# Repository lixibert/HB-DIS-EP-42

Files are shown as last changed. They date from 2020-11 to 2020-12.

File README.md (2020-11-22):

# HB-DIS-EP-42 

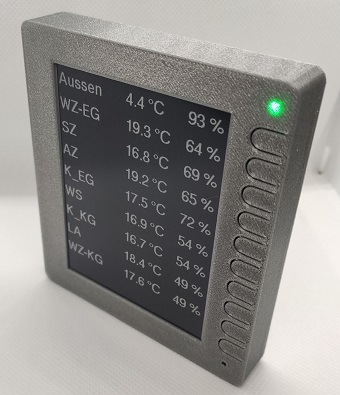
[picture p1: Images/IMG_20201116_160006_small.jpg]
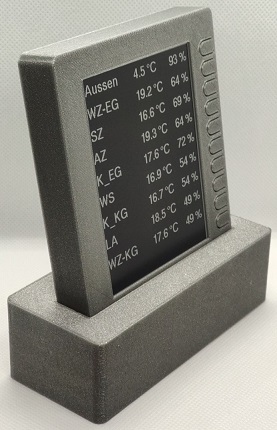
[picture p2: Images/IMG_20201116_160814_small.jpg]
 

Die Infos hier beziehen sich auf Jérômes Projekt ePaper Display HB-Dis-EP-42BW  
[Original HB-Dis-EP-42BW](https://github.com/jp112sdl/HB-Dis-EP-42BW)

Support thread: https://homematic-forum.de/forum/viewtopic.php?f=76&t=61624

## Danke an  

Marco (stan23) für das ursprüngliche Leiterplattendesign welches Ausgangspunkt für diese Variante war  
papa für die Bereitstellung der AskSinPP Library  
TomMajor für die guten Tipps und den genialen Script-Helper  
Jérôme für Alles ;-)  

# Warum noch eine Variante?
Einerseits hat sich das e-Paper-Display von Waveshare geändert (Rev.2.1) und ich  wollte eine Gehäusevariante für die Wandmontage haben.
Hier hätten normale AA Batterien zu viel Platz beansprucht und das Gehäuse wäre entweder zu dick
oder zu lang geworden. Also musste eine Lösung mit Li-Po Akku her.

Außerdem hat man mehrere Möglichkeiten zur Stromversorgung  

- AA/AAA Batterien oder Akkus mit/ohne Stepup Regler  
- Li-Po Akku  
- Netzbetrieb mit 5V Netzteil  über Micro-USB Buchse  

Während des Ladevorgangs leuchten beide Leds (Duoled) solange bis der Akku vollgeladen ist. 

# Sketch  
Die Firmware stammt von Jérôme und wurde nur durch den Teil für den Li-Po Akku erweitert.  
Dazu einfach im Code  
`#define LIPO`  
auskommentieren. (Standard ist bereits auskommentiert)  
Für die Varianten ohne Li-Po kann man wahlweise auch die originale Version von Jérôme laden.    
https://github.com/jp112sdl/HB-Dis-EP-42BW/blob/master/HB-Dis-EP-42BW.ino

# Schaltung
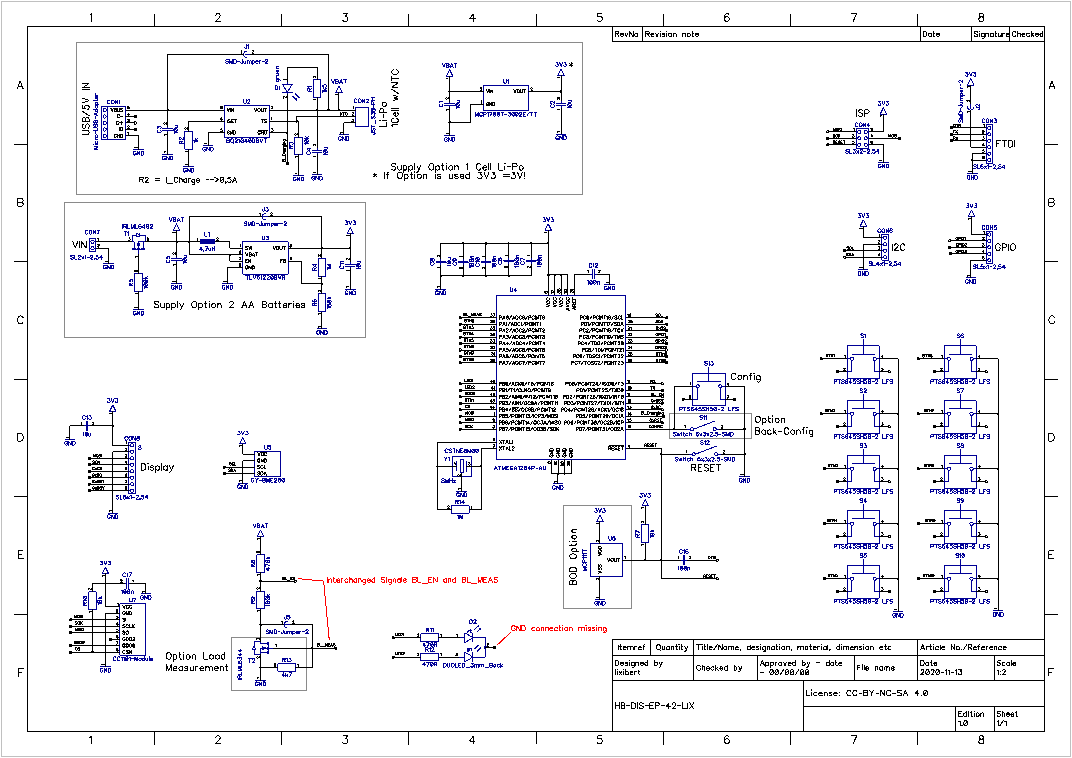
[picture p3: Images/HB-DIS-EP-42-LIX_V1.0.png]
  
In der ersten Version gibt es leider noch 2 Fehler im Schaltplan (rot markiert) ,  
die sich jedoch auf der Platine sehr leicht beheben lasssen.  
Die beiden Signale um die Batteriespannung zu messen (BL_EN und BL_MEAS) sind vertauscht.  
Auf der Platine muß daher R8 (470k) und R9 (100k) etwas anders bestückt werden.  
Lötjumper J5 muß geschlossen werden.  

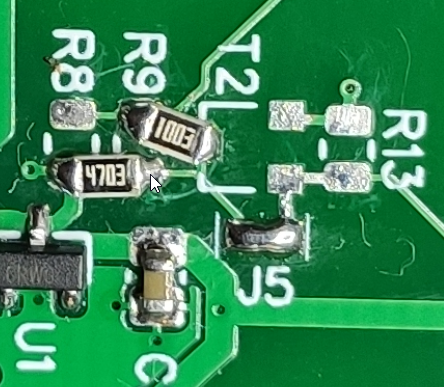
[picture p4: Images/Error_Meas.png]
  
Bei der Duoled fehlt die Masseanbindung. Dazu muß nur etwas Lötstopplack weggekratzt werden  
und mit Lötzinn verbunden werden.  
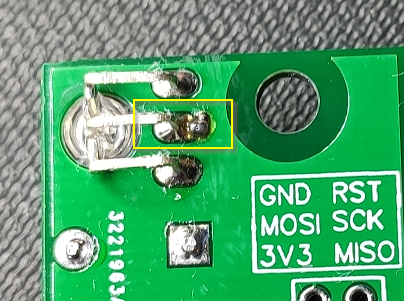
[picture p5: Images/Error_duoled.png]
  
Bei Bedarf werde ich die Daten noch bereinigen und eine neue Version erstellen.  
Zur Zeit habe ich jedoch noch einige Leiterplatten vorrätig, so dass da für mich keine Notwendigkeit  besteht.  

# Platine  
[**Gerberdaten**](PCB/HB-DIS-EP-42-LIX_gerberx2.zip)  
[**Stückliste**](PCB/Stückliste_HB-DIS-EP-42_V1.0.pdf)  

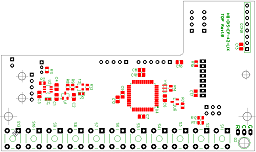
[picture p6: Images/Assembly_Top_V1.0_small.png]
  

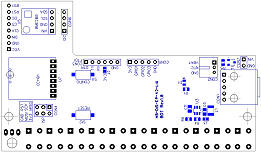
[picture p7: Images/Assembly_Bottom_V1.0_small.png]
  

# Mechanik
Das Gehäuse besteht  aus einem [Frontrahmen](Mechanik/Frontrahmen.stl) in welchem die Leiterplatte mit dem  Display eingeklebt wird  
und aus einer [Rückwand](Mechanik/Rückwand.stl) die einfach auf den Frontrahmen geclipst wird.  
Auf die Innenseite der Rückwand können z. B. auch Magnete geklebt werden.  
In meinem Fall befindet sich eine Holzkonsole an der Wand, in die ebenfalls Magnete eingklebt wurden.  
Somit kann man das Display sowohl als Tischmodel, als auch an der Wand benutzen.   

Zusätzlich gibt es noch einen [Sockel](Mechanik/Sockel.stl) mit [Batteriefach](Sockelverschluss.stl) an der Unterseite.  
Es gibt die Möglichkeit im Frontrahmen und am Sockel Magnete (10x5x2mm) einzukleben.  
Damit sitzt das Display dann fest im Sockel.  
Der Sockel wird für die Variante mit AA/AAA Batterien zwingend benötigt, da nur hier genug Platz für die Batteriebox ist.  
Die max. Abmessungen für eine Batteriebox sind l/b/h = 114 x 44 x 20mm.  
Somit ist eine Montage an der Wand nur mit Li-Po Akku möglich.  

# Aufbau  
**Wichtig! Display und Platine erst nach der Verschraubung verlöten**  
Das Display wird mit der Platine mit 2 Senkkopfschrauben M3x10 verschraubt.  
Wichtig ist, das der Abstand zwischen Display und Platine 2mm beträgt, damit die Taster bündig mit dem Frontrahmen sind!  
Die Schrauben sollten noch nicht ganz fest angezogen werden.  

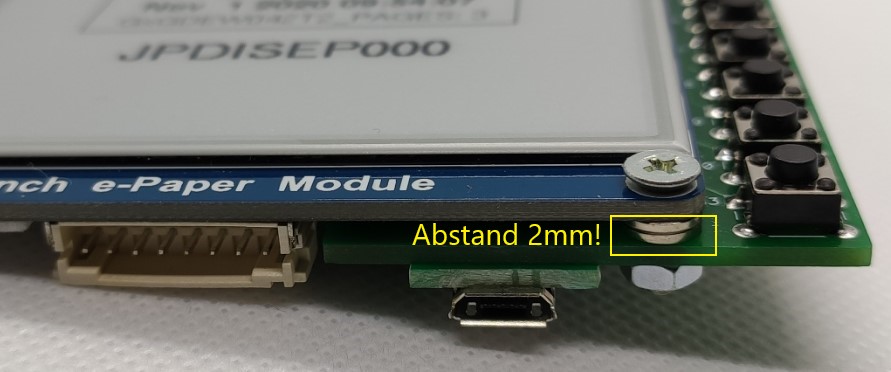
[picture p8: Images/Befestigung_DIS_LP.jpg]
  

Nun werden die 2 Magnete in den Frontrahmen an die Unterseite geklebt.  

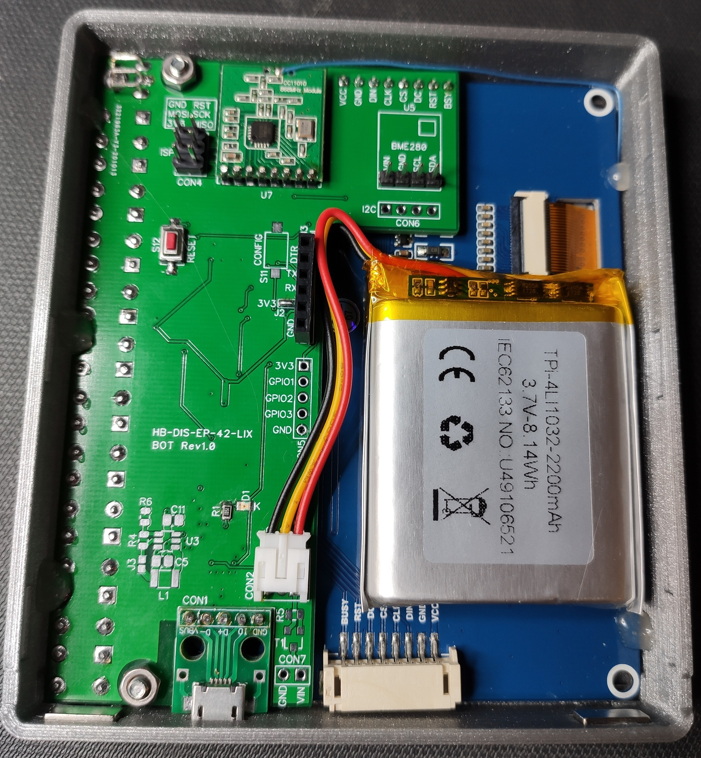
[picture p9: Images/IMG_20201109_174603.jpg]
  

Dannn die Einheit in den Frontrahmen setzen und darauf achten dass das Display bündig mit der Vorderseite abschliesst.  
Erst jetzt werden die beiden M3 Muttern angezogen. Das Display kann danach mit der Platine verlötet werden.  
Anschliessend wird die Displayeinheit noch mit Heisskleber im Frontrahmen fixiert.  
Der Li-Po wird mit Montageklebeband auf das Display geklebt.  
Das Klebeband sollte mindestens 1mm Stärke haben, damit die Bauteile am Display nicht beschädigt werden.  

Jetzt noch 2 Magnete in den Sockel einkleben,  

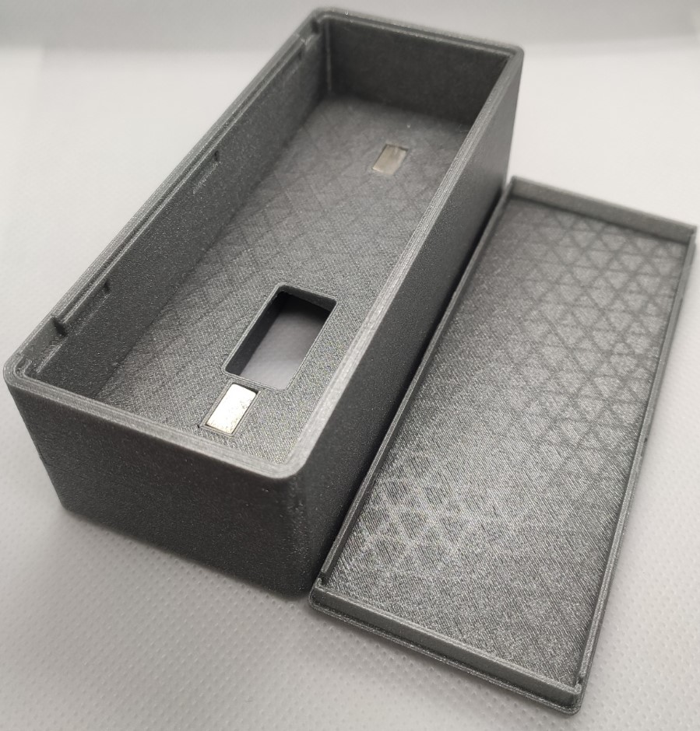
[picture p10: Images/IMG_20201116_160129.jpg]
  

und bei Bedarf noch zusätzliche Magnete in die Rückwand kleben.  

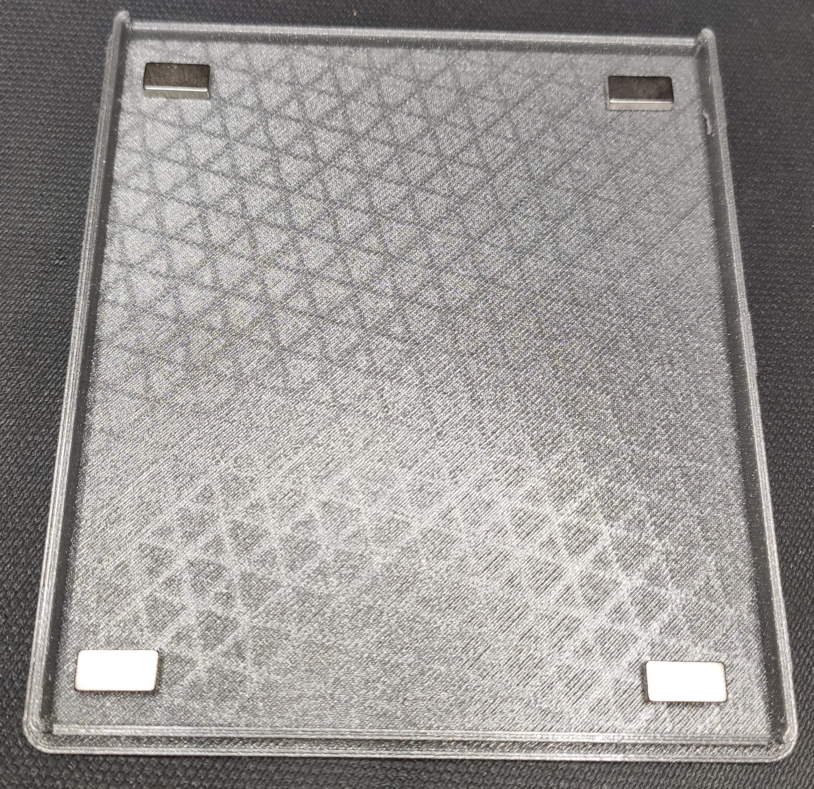
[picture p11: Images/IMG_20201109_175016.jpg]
  

# Zusätzliches Material

ein paar Magnete  10x5x2mm (benötigt werden min. 4 Stk.) z. B. https://www.amazon.de/First4magnets-F1052-10-Neodym-Magnete-ziehen-Packung/dp/B010DOW2OO/  
Li-Po Akku z.B. https://www.ebay.de/itm/LiPo-Polymer-Li-Ion-Akku-3-7V-2200mAh-54x42x8-5mm-JST-PH-3-Elektronik-NTC/324239268082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  
2 x M3x10 Senkkopfschrauben  
2 x Mutter M3  
2 x Abstandhalter 2mm  
4,2 Zoll E-ink Display https://de.aliexpress.com/item/32967154643.html?spm=a2g0s.9042311.0.0.27424c4dhfQJNQ oder  
https://www.amazon.de/Waveshare-Kommunikation-Schnittstelle-Aufl%C3%B6sung-Embedded-Controller/dp/B074NR1SW2  

# Kommt noch was?  
zur Zeit laufen gerade Versuche mit Qi Wireless Charging.

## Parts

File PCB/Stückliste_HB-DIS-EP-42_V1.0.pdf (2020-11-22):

Seite 1

| | | | Bestückungsvarianten B = Bestückt O = Optional X = nicht bestückt
Name | Bauform | Wert | Referenz | 2 x AA Batteries Mit Stepup | 2 x AA Batteries Ohne Stepup | Li-Po | Netzteil | Bezugsquelle | Bemerkung
10u_X5R_16V | 0805 | 10u | C1 | x | x | B | B | Reichelt: X5R-G0805 10/16
10u_X5R_16V | 0805 | 10u | C2 | x | x | B | B | Reichelt: X5R-G0805 10/16
10u_X5R_16V | 0805 | 10u | C3 | x | x | B | x | Reichelt: X5R-G0805 10/16
10u_X5R_16V | 0805 | 10u | C4 | x | x | B | x | Reichelt: X5R-G0805 10/16
10u_X5R_16V | 0805 | 10u | C5 | B | x | x | x | Reichelt: X5R-G0805 10/16
100n_X7R_50V | 0805 | 100n | C6 | B | B | B | B | Reichelt: X7R-G0805 100N
100n_X7R_50V | 0805 | 100n | C7 | B | B | B | B | Reichelt: X7R-G0805 100N
10u_X5R_16V | 0805 | 10u | C8 | B | B | B | B | Reichelt: X5R-G0805 10/16
100n_X7R_50V | 0805 | 100n | C9 | B | B | B | B | Reichelt: X7R-G0805 100N
100n_X7R_50V | 0805 | 100n | C10 | B | B | B | B | Reichelt: X7R-G0805 100N
10u_X5R_16V | 0805 | 10u | C11 | B | B | x | x | Reichelt: X5R-G0805 10/16
100n_X7R_50V | 0805 | 100n | C12 | B | B | B | B | Reichelt: X7R-G0805 100N
10u_X5R_16V | 0805 | 10u | C13 | B | B | B | B | Reichelt: X5R-G0805 10/16
100n_X7R_50V | 0805 | 100n | C16 | B | B | B | B | Reichelt: X7R-G0805 100N
100n_X7R_50V | 0805 | 100n | C17 | B | B | B | B | Reichelt: X7R-G0805 100N
Micro-USB-Adapter | | | CON1 | x | x | O | O | Reichelt: DEBO MICROUSB 2
JST_S3B-PH | 2mm | 3 CON2 | | x | x | B | x | Reichelt: JST EH3P ST90 | nur für Li-Po Akku mit NTC notwendig
SL6x1-2,54 | 2,54 | 6 CON3 | | O | O | O | O | | Optionale Buchsenleiste für FTDI Adpater
SL3x2-2,54 | 2,54 | 6 CON4 | | O | O | O | O | | OptionaleStiftleiste für ISP
SL5x1-2,54 | 2,54 | 5 CON5 | | x | x | x | x | | zur Zeit nicht benötigt
SL4x1-2,54 | 2,54 | 4 CON6 | | x | x | x | x | | zur Zeit nicht benötigt
SL2x1-2,54 | 2,54 | 2 CON7 | | O | O | x | x | | Kabel für Batteriebox direkt anlöten
SL8x1-2,54 | 2,54 | 8 CON8 | | B | B | B | B
LED_gruen | 0805 | gruen | D1 | x | x | O | x | Reichelt: SMD-LED 0805 GN
DUOLED_3mm_Back | | | D2 | B | B | B | B | Reichelt: EVL 209SURSYGW | Anschlüsse vorab 180° biegen
SMD-Jumper-2 | | | J1 | offen | offen | x | geschlossen
SMD-Jumper-2 | | | J2 | O | O | O | O
SMD-Jumper-2 | | | J3 | offen | geschlossen | offen | offen
SMD-Jumper-2 | | | J5 | geschlossen | geschlossen | geschlossen | geschlossen
4,7µH | 1210 | 4,7uH | L1 | B | x | x | x | Reichelt: LQH3C 4,7µ
1k5 | 0805 | 1k5 | R1 | x | x | O | x
10k | 0805 | 10k | R10 | O | O | O | O
470R | 0805 | 470R | R11 | B | B | B | B
470R | 0805 | 470R | R12 | B | B | B | B
4k7 | 0805 | 4k7 | R13 | x | x | x | x
1M | 0805 | 1M | R14 | O | O | O | O
1k | 0805 | 1k | R2 | x | x | B | x
10k | 0805 | 10k | R3 | x | x | O | x
1M | 0805 | 1M | R4 | B | x | x | x
100k | 0805 | 100k | R5 | B | B | x | x
180k | 0805 | 180k | R6 | B | x | x | x
10k | 0805 | 10k | R7 | B | B | B | B
470k | 0805 | 470k | R8 | B | B | B | B

Seite 2

100k | 0805 | 100k | R9 | B | B | B | B
PTS645SH50-2 LFS | | | S1 | B | B | B | B | Reichelt: TASTER 9302 | 5mm Bauhöhe
PTS645SH50-2 LFS | | | S2 | B | B | B | B | Reichelt: TASTER 9302 | 5mm Bauhöhe
PTS645SH50-2 LFS | | | S3 | B | B | B | B | Reichelt: TASTER 9302 | 5mm Bauhöhe
PTS645SH50-2 LFS | | | S4 | B | B | B | B | Reichelt: TASTER 9302 | 5mm Bauhöhe
PTS645SH50-2 LFS | | | S5 | B | B | B | B | Reichelt: TASTER 9302 | 5mm Bauhöhe
PTS645SH50-2 LFS | | | S6 | B | B | B | B | Reichelt: TASTER 9302 | 5mm Bauhöhe
PTS645SH50-2 LFS | | | S7 | B | B | B | B | Reichelt: TASTER 9302 | 5mm Bauhöhe
PTS645SH50-2 LFS | | | S8 | B | B | B | B | Reichelt: TASTER 9302 | 5mm Bauhöhe
PTS645SH50-2 LFS | | | S9 | B | B | B | B | Reichelt: TASTER 9302 | 5mm Bauhöhe
PTS645SH50-2 LFS | | | S10 | B | B | B | B | Reichelt: TASTER 9302 | 5mm Bauhöhe
Switch 6x3x2.5-SMD | | | S11 | O | O | O | O | https://de.aliexpress.com/item/32897450033.html
Switch 6x3x2.5-SMD | | | S12 | O | O | O | O | https://de.aliexpress.com/item/32897450033.html
PTS645SH50-2 LFS | | | S13 | B | B | B | B | Reichelt: TASTER 9302 | 5mm Bauhöhe
IRLML6402 | SOT-23 | | T1 | B | B | x | x | Reichelt: IRLML 6402
IRLML6344 | SOT-23 | | T2 | x | x | x | x | Reichelt: IRLML 6344
MCP1700T-3002E/TT | SOT-23 | | U1 | x | x | B | B | Reichelt: MCP 1700T-3002E
BQ21040DBV | SOT23-6 | | U2 | x | x | B | B | https://de.aliexpress.com/item/1005001492820837.html
TLV61220BVR | SOT23-6 | | U3 | B | x | x | x | https://de.aliexpress.com/item/1005001490512917.html
ATMEGA1284P-AU | TQFP-44 | | U4 | B | B | B | B | Reichelt: ATMEGA 1284P-AU
GY-BME280 | | | U5 | x | x | x | x | | zur Zeit nicht benötigt
MCP111T-240E/TT | | | U6 | x | O | x | x
CC1101-Module | | | U7 | B | x | B | B | https://de.aliexpress.com/item/32951998715.html
CSTNE8M00 | | 8MHz | Y1 | O | O | O | O | https://de.aliexpress.com/item/32958792628.html

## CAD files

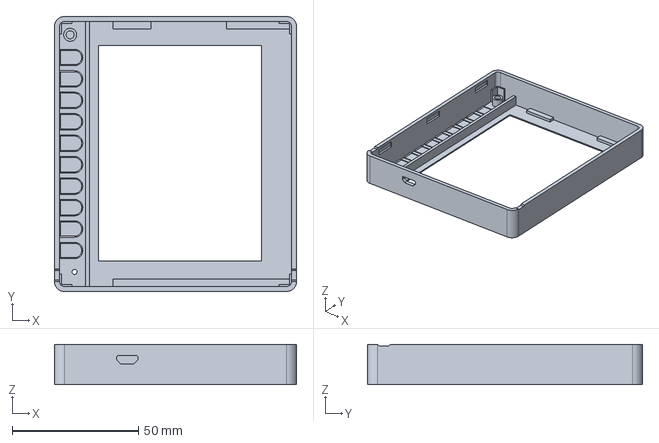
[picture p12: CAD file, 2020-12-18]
Mechanik/Frontrahmen.stp
96.0 x 109.0 x 16.0 mm

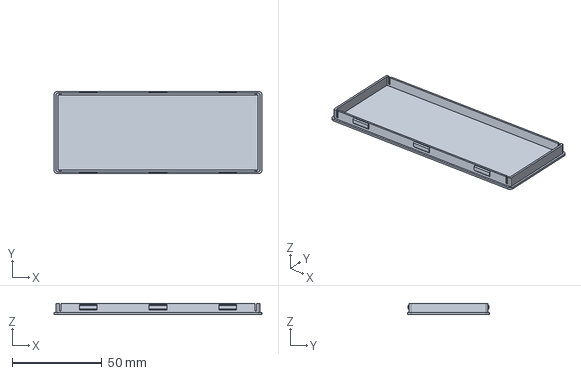
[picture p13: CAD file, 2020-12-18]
Mechanik/Sockelverschluss.stp
116.0 x 46.0 x 6.00 mm

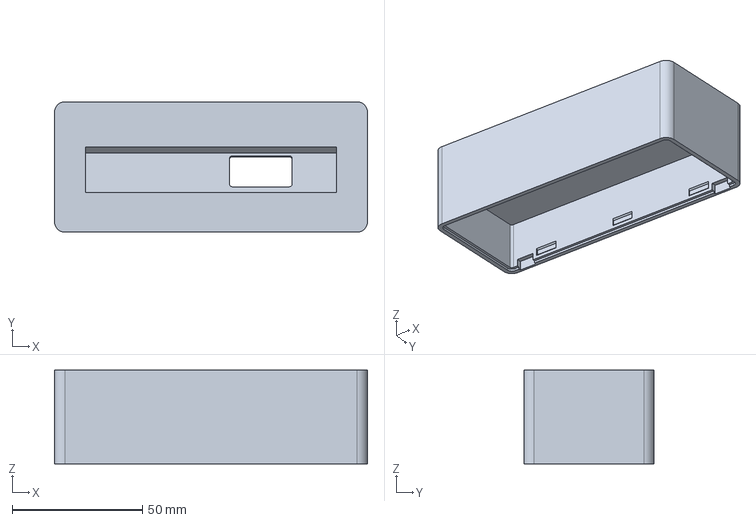
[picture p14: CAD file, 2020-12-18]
Mechanik/Sockel.stp
120.0 x 50.0 x 36.0 mm

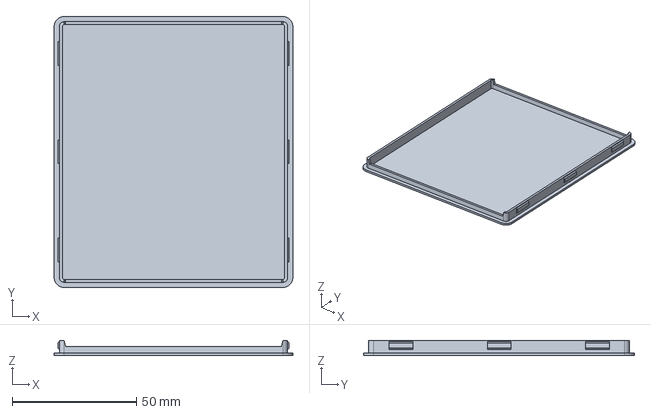
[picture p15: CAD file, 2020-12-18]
Mechanik/Rückwand.stp
96.0 x 109.0 x 6.00 mm

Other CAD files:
Mechanik/Frontrahmen.stl
Mechanik/Rückwand.stl
Mechanik/Sockel.stl
Mechanik/Sockelverschluss.stl

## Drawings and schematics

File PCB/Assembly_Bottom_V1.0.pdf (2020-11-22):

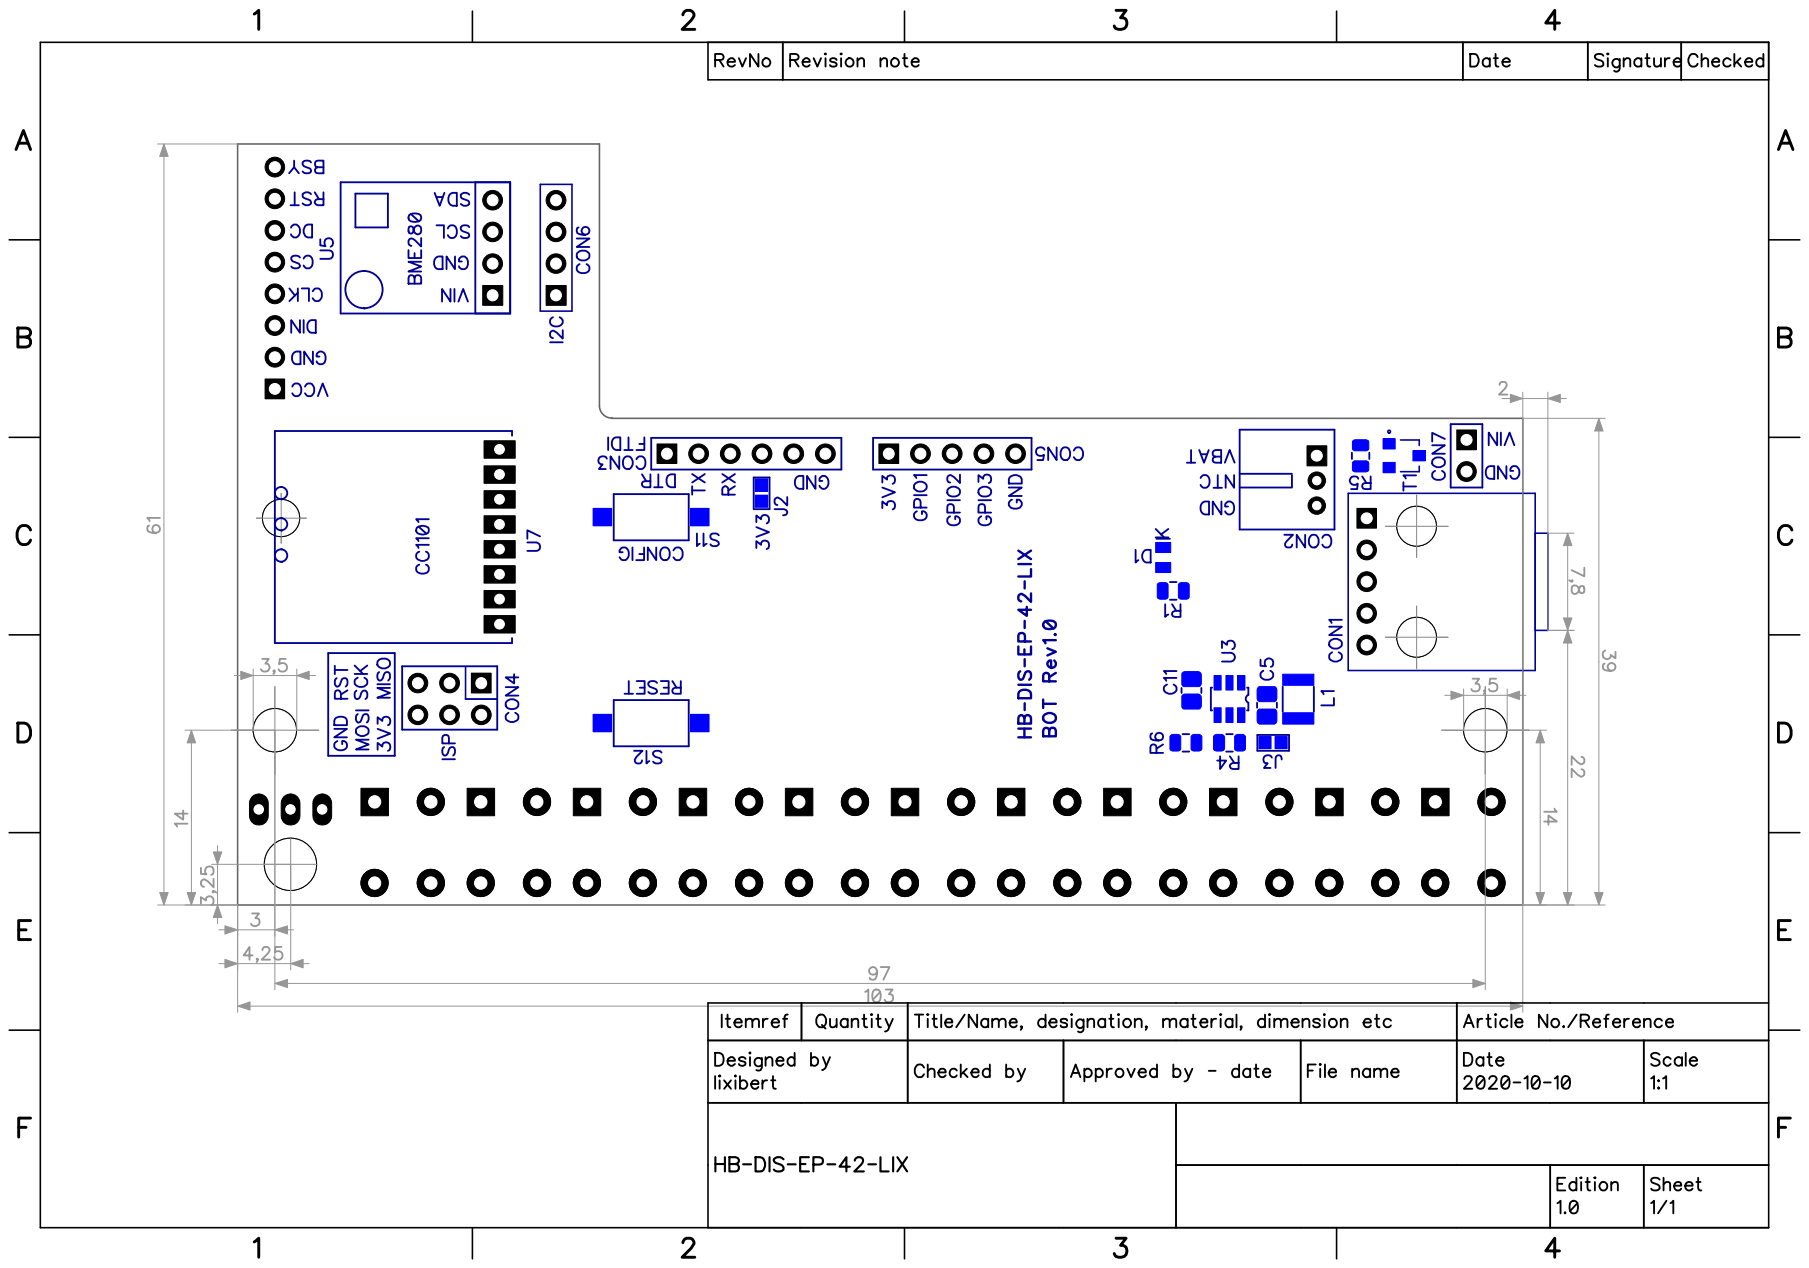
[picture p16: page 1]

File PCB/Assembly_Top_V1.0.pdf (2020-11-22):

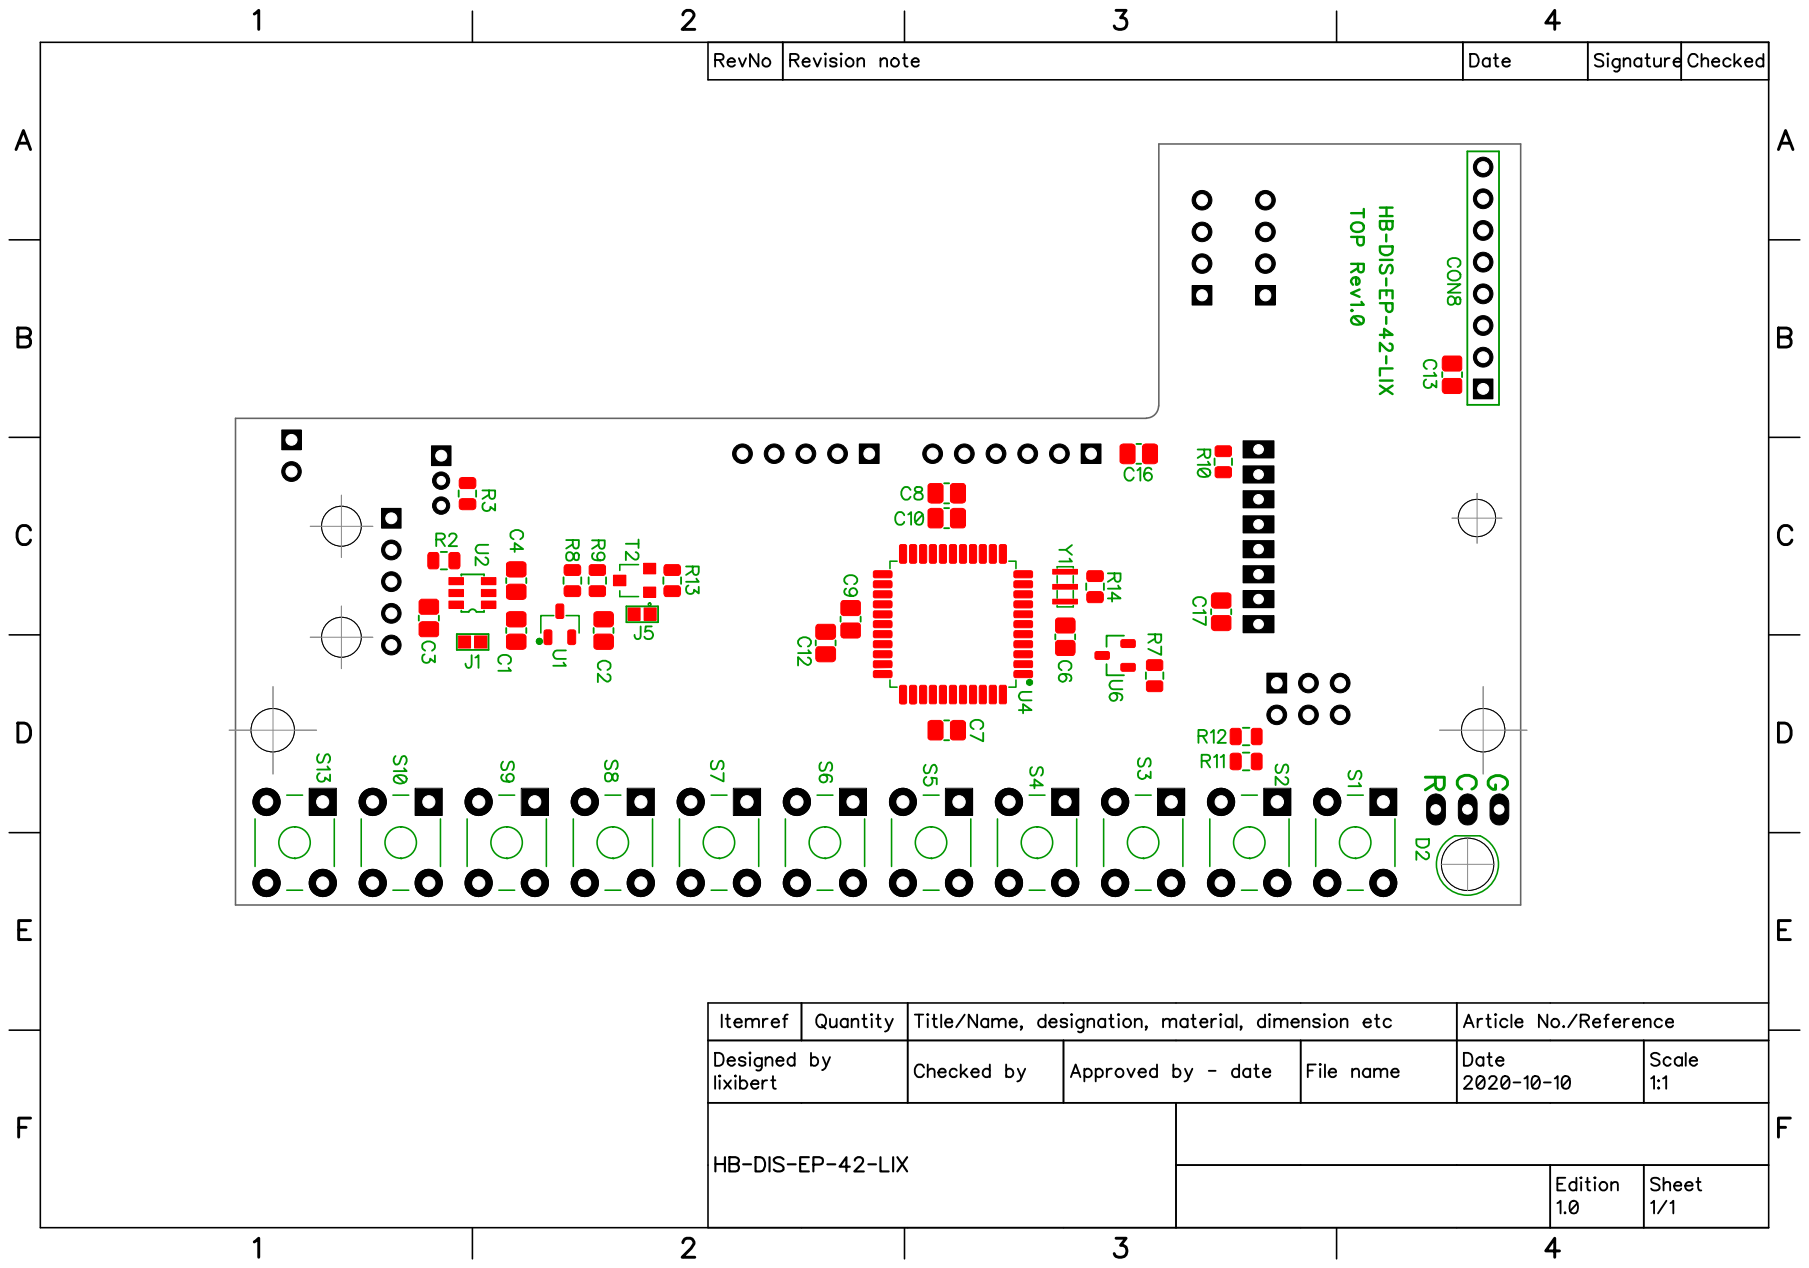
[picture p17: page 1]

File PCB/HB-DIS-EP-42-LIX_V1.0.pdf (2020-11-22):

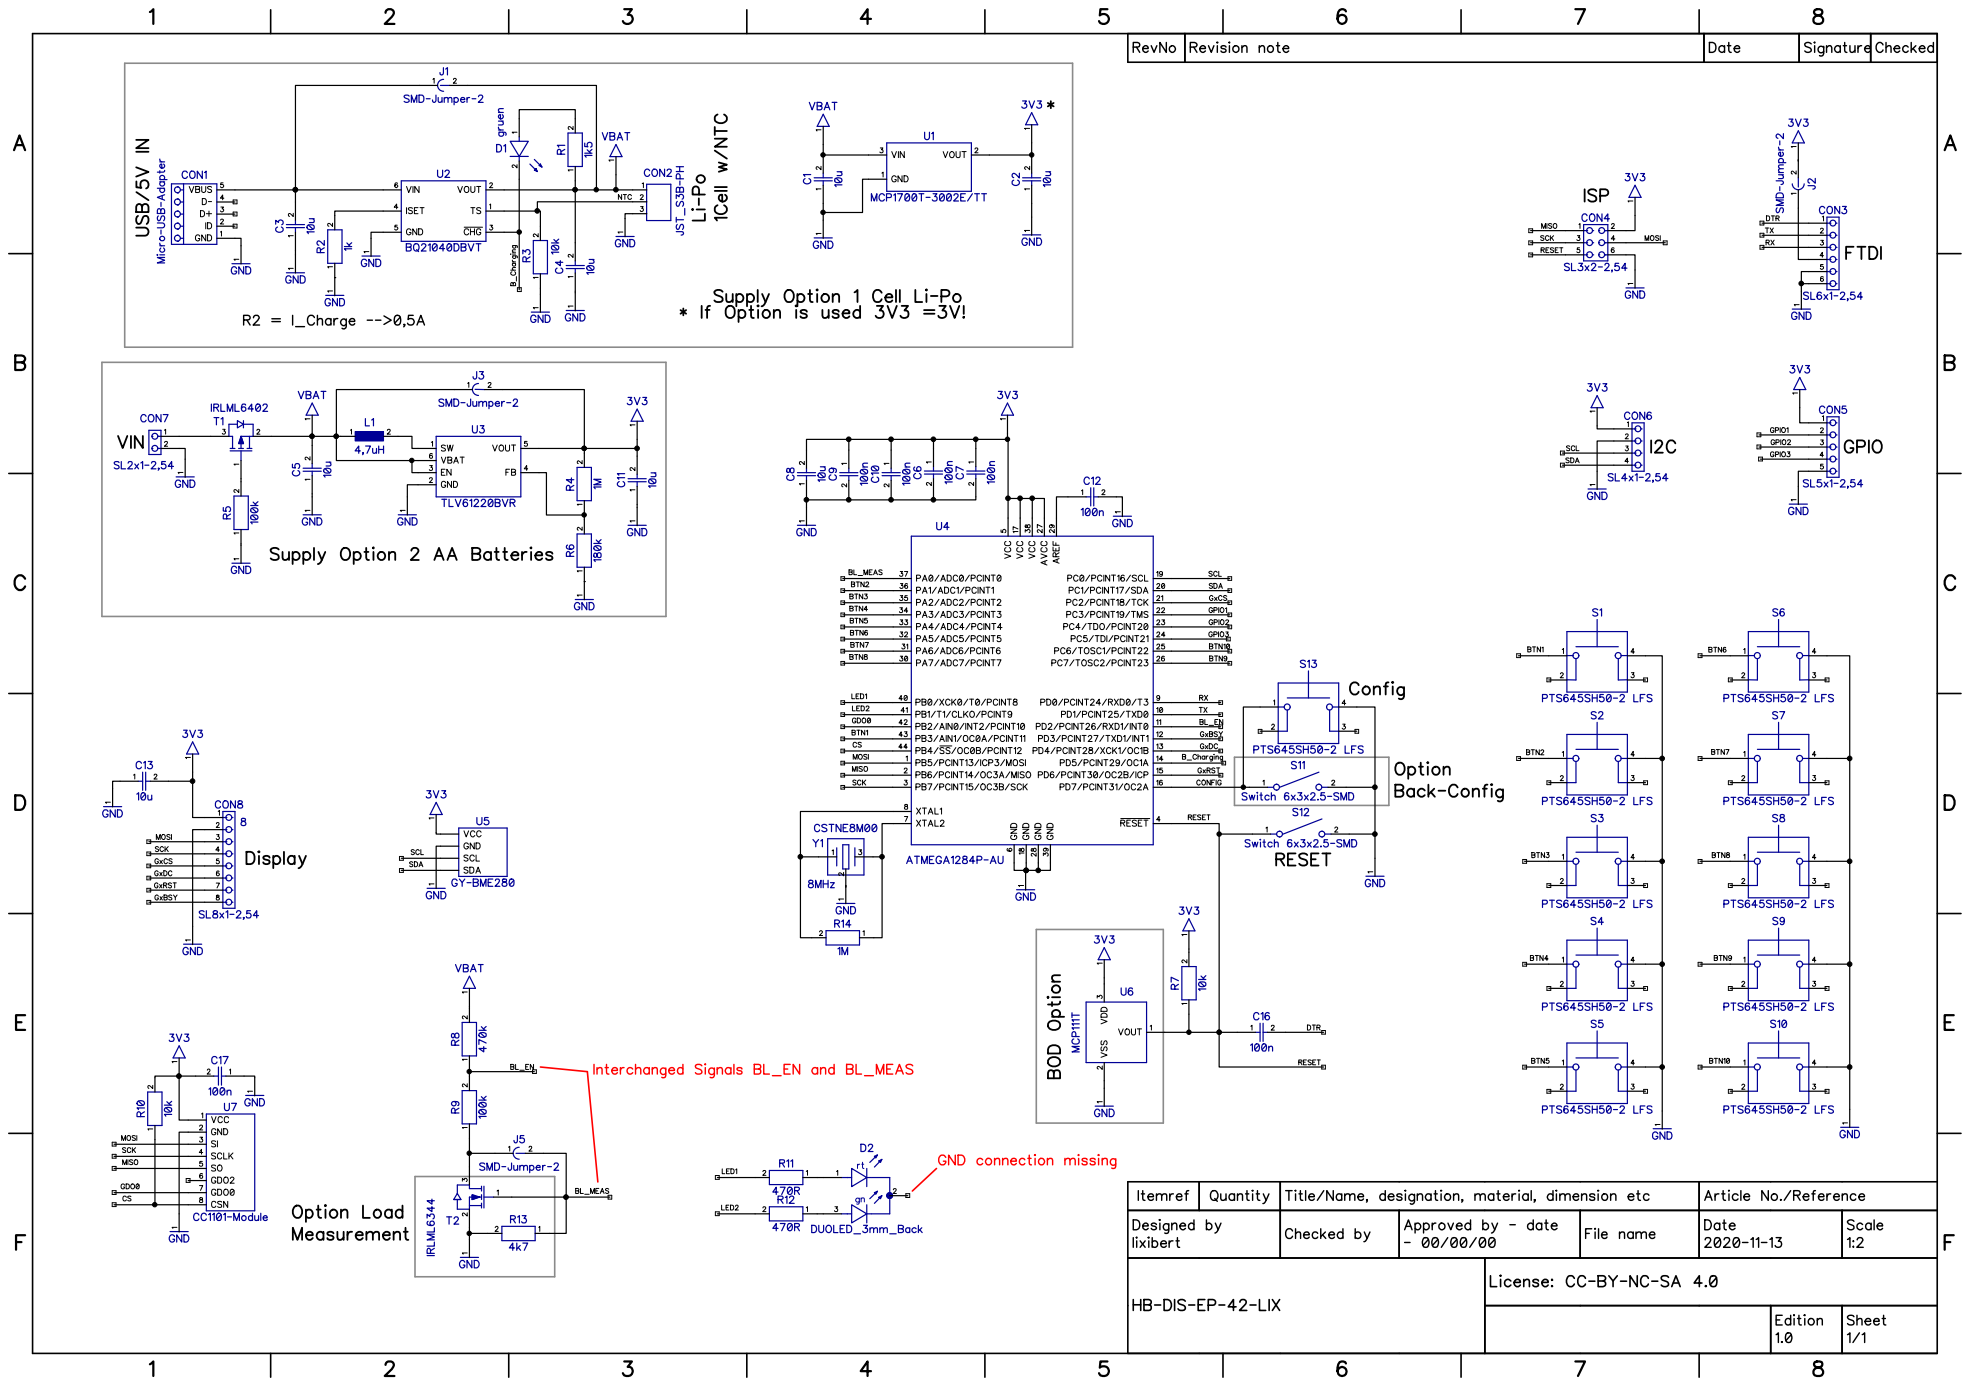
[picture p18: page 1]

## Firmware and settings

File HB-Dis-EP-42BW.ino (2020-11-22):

//- -----------------------------------------------------------------------------------------------------------------------
// AskSin++
// 2016-10-31 papa Creative Commons - http://creativecommons.org/licenses/by-nc-sa/3.0/de/
// 2018-12-01 jp112sdl Creative Commons - http://creativecommons.org/licenses/by-nc-sa/3.0/de/
//- -----------------------------------------------------------------------------------------------------------------------

// use Arduino IDE Board Setting: STANDARD Layout

// define this to read the device id, serial and device type from bootloader section
// #define USE_OTA_BOOTLOADER
// #define USE_HW_SERIAL
// #define NDEBUG
// #define NDISPLAY
// #define USE_COLOR

#define BATTERY_MODE
#define LIPO

#ifdef BATTERY_MODE
#define USE_WOR
#endif

//////////////////// DISPLAY DEFINITIONS /////////////////////////////////////
#include <GxEPD.h>
#ifdef USE_COLOR
#include <GxGDEW042Z15/GxGDEW042Z15.h>      // 4.2" color
#else
#include <GxGDEW042T2/GxGDEW042T2.h>        // 4.2" b/w Don't forget to change Reset Pin settings in GxDEW042xxx.cpp
#endif

#include <GxIO/GxIO_SPI/GxIO_SPI.h>
#include <GxIO/GxIO.h>
#include "U8G2_FONTS_GFX.h"

#define GxRST_PIN  14   // PD6
#define GxBUSY_PIN 11   // PD3
#define GxDC_PIN   12   // PD4
#define GxCS_PIN   18   // PC2

GxIO_Class io(SPI, GxCS_PIN, GxDC_PIN, GxRST_PIN);
GxEPD_Class display(io, GxRST_PIN, GxBUSY_PIN);

U8G2_FONTS_GFX u8g2Fonts(display);
//////////////////////////////////////////////////////////////////////////////

#define EI_NOTEXTERNAL
#include <EnableInterrupt.h>

#include <AskSinPP.h>
#include <LowPower.h>

#include <Register.h>
#include <Remote.h>
#include <MultiChannelDevice.h>

#define CC1101_CS_PIN       4   // PB4
#define CC1101_GDO0_PIN     2   // PB2
#define CC1101_SCK_PIN      7   // PB7
#define CC1101_MOSI_PIN     5   // PB5
#define CC1101_MISO_PIN     6   // PB6
#define CONFIG_BUTTON_PIN  15   // PD7
#define LED_PIN_1           0   // PB0
#define LED_PIN_2           1   // PB1
#define BTN1_PIN            3   // PB3
#define BTN2_PIN           A1   // PA1
#define BTN3_PIN           A2   // PA2
#define BTN4_PIN           A3   // PA3
#define BTN5_PIN           A4   // PA4
#define BTN6_PIN           A5   // PA5
#define BTN7_PIN           A6   // PA6
#define BTN8_PIN           A7   // PA7
#define BTN9_PIN           23   // PC7
#define BTN10_PIN          22   // PC6
#define B_CHARGING_PIN     13   // PD5 Led Output BQ21040 - pulled low when charging

#define TEXT_LENGTH        16
#define DISPLAY_LINES      10

#define DISPLAY_ROTATE     3 // 0 = 0° , 1 = 90°, 2 = 180°, 3 = 270°

#define PEERS_PER_CHANNEL   8
#define NUM_CHANNELS        11
#define DEF_LOWBAT_VOLTAGE  34
#define DEF_CRITBAT_VOLTAGE 33

#define MSG_START_KEY     0x02
#define MSG_TEXT_KEY      0x12
#define MSG_ICON_KEY      0x13
#define MSG_COLOR_OFFSET  0x04
#define MSG_CLR_LINE_KEY  0xFE
#define MSG_MIN_LENGTH    13
#define MSG_BUFFER_LENGTH 224
#define MSG_OUTOFHOUSE    0xFD

#include "Icons.h"

// all library classes are placed in the namespace 'as'
using namespace as;

const struct DeviceInfo PROGMEM devinfo = {
  {0xf3, 0x43, 0x00},          // Device ID
  "JPDISEP000",                // Device Serial
#ifdef BATTERY_MODE
  {0xf3, 0x43},                // Device Model
#else
  {0xf3, 0x53},                // Device Model
#endif
  0x11,                        // Firmware Version
  as::DeviceType::Remote,      // Device Type
  {0x01, 0x01}                 // Info Bytes
};

enum Alignments {AlignRight = 0, AlignCenterIconRight = 1, AlignCenterIconLeft = 3, AlignLeft = 2};

typedef struct {
  uint8_t Alignment = AlignRight;
  uint8_t Icon      = 0xff;
  bool IconColored  = false;
  String Text       = "";
  bool TextColored  = false;
  bool showLine     = false;
} DisplayLine;
DisplayLine DisplayLines[DISPLAY_LINES];

String List1Texts[DISPLAY_LINES * 2];

bool runSetup          = true;

volatile bool isr_chrg_state = false;
/**
   Configure the used hardware
*/
typedef AvrSPI<CC1101_CS_PIN, CC1101_MOSI_PIN, CC1101_MISO_PIN, CC1101_SCK_PIN> SPIType;
typedef Radio<SPIType, CC1101_GDO0_PIN> RadioType;
typedef StatusLed<LED_PIN_1> LedType;

#ifdef BATTERY_MODE
typedef IrqExternalBatt<A0, 10, 59> BatterySensorType; // Batterymeasurement under real load conditions 
typedef AskSin<LedType, BatterySensorType, RadioType> BaseHal;
#else
typedef AskSin<LedType, NoBattery, RadioType> BaseHal;
#endif

class Hal: public BaseHal {
  public:
    void init(const HMID& id) {
      BaseHal::init(id);
#ifdef BATTERY_MODE
      battery.init(seconds2ticks(12UL * 60 * 60), sysclock); //battery measure every 12 hours
      battery.low(DEF_LOWBAT_VOLTAGE);
      battery.critical(DEF_CRITBAT_VOLTAGE);
      activity.stayAwake(seconds2ticks(15));
#endif
    }

    bool runready () {
      return sysclock.runready() || BaseHal::runready();
    }
} hal;

#ifdef LIPO
// Beide Led`s einschalten während Ladevorgang
void charger_status() {
  isr_chrg_state = digitalRead(B_CHARGING_PIN);
  digitalWrite(LED_PIN_1, !isr_chrg_state);
  digitalWrite(LED_PIN_2, !isr_chrg_state);
}
#endif

void initDisplay();
void updateDisplay();
void emptyBatteryDisplay();
void outOfHouseDisplay();
class ePaperType : public Alarm {
  class ePaperWorkingLedType : public StatusLed<LED_PIN_2>  {
  private:
    bool enabled;
  public:
    ePaperWorkingLedType () : enabled(true) {}
    virtual ~ePaperWorkingLedType () {}
    void Enabled(bool e) {
      enabled = e;
    }
    bool Enabled() {
      return enabled;
    }
  } workingLed;
private:
  bool                 mUpdateDisplay;
  bool                 shInitDisplay;
  bool                 shOutOfHouseDisplay;
  bool                 inverted;
  bool                 waiting;
  uint16_t             clFG;
  uint16_t             clBG;
public:
  ePaperType () :  Alarm(0), mUpdateDisplay(false), shInitDisplay(false), shOutOfHouseDisplay(false), inverted(false), waiting(false), clFG(GxEPD_BLACK), clBG(GxEPD_WHITE)  {}
  virtual ~ePaperType () {}

  uint16_t ForegroundColor() {
    return clFG;
  }

  void ForegroundColor(uint16_t c) {
    clFG = c;
  }

  uint16_t BackgroundColor() {
    return clBG;
  }

  void BackgroundColor(uint16_t c) {
    clBG = c;
  }

  bool Inverted() {
    return inverted;
  }

  void Inverted(bool i) {
    inverted = i;
  }

  bool showInitDisplay() {
    return shInitDisplay;
  }

  void showInitDisplay(bool s) {
    shInitDisplay = s;
  }

  bool showOutOfHouseDisplay() {
    return shOutOfHouseDisplay;
  }

  void showOutOfHouseDisplay(bool s) {
    shOutOfHouseDisplay = s;
  }

  bool mustUpdateDisplay() {
    return mUpdateDisplay;
  }

  void mustUpdateDisplay(bool m) {
    if (m == true && workingLed.Enabled() == true) workingLed.set(LedStates::pairing);
    mUpdateDisplay = m;
  }

  void init() {
    u8g2Fonts.begin(display);
    display.setRotation(DISPLAY_ROTATE);
    u8g2Fonts.setFontMode(1);
    u8g2Fonts.setFontDirection(0);
    workingLed.init();
  }

  void setWorkingLedEnabled(bool en) {
    workingLed.Enabled(en);
  }

  void setDisplayColors() {
    u8g2Fonts.setForegroundColor(ForegroundColor());
    u8g2Fonts.setBackgroundColor(BackgroundColor());
  }

  void isWaiting(bool w) {
    waiting = w;
    DPRINT("wait:"); DDECLN(waiting);
  }

  bool isWaiting() {
    return waiting;
  }

  void setRefreshAlarm (uint32_t t) {
    isWaiting(true);
    sysclock.cancel(*this);
    Alarm::set(millis2ticks(t));
    sysclock.add(*this);
  }
  virtual void trigger (__attribute__((unused)) AlarmClock& clock) {
    isWaiting(false);
    if (this->mustUpdateDisplay()) {
      this->mustUpdateDisplay(false);
  #ifndef NDISPLAY
      if (workingLed.Enabled() == true) {
        workingLed.set(LedStates::nothing);
        workingLed.ledOn();
      }
      setDisplayColors();
      if (this->showInitDisplay() == true) {
        this->showInitDisplay(false);
        display.drawPaged(initDisplay);
      } else if (this->showOutOfHouseDisplay() == true ) {
          display.drawPaged(outOfHouseDisplay);
          this->showOutOfHouseDisplay(false);
        } else {
          display.drawPaged(updateDisplay);
        }

      workingLed.ledOff();
  #else
      DPRINTLN("UPDATEDISPLAY!");
  #endif
    }
  }
} ePaper;

DEFREGISTER(Reg0, MASTERID_REGS, DREG_TRANSMITTRYMAX, DREG_LEDMODE, DREG_LOWBATLIMIT, 0x06, 0x07, 0x34, 0x35)
class DispList0 : public RegList0<Reg0> {
  public:
    DispList0(uint16_t addr) : RegList0<Reg0>(addr) {}

    bool displayInvertingHb(bool v) const { return this->writeRegister(0x06, 0x01,0,v); }
    bool displayInvertingHb() const { return this->readRegister(0x06, 0x01,0,false); }

    uint8_t displayRefreshWaitTime () const { return this->readRegister(0x07,0); }
    bool displayRefreshWaitTime (uint8_t value) const { return this->writeRegister(0x07,value); }

    uint8_t powerUpMode () const { return this->readRegister(0x34,0x03,0); }
    bool powerUpMode (uint8_t value) const { return this->writeRegister(0x34,0x03,0,value); }

    uint8_t powerUpKey () const { return this->readRegister(0x34,0x0f,2); }
    bool powerUpKey (uint8_t value) const { return this->writeRegister(0x34,0x0f,2,value); }

    uint8_t critBatLimit () const { return this->readRegister(0x35,0); }
    bool critBatLimit (uint8_t value) const { return this->writeRegister(0x35,value); }

    void defaults () {
      clear();
      displayInvertingHb(false);
      ledMode(1);
      transmitDevTryMax(2);
      displayRefreshWaitTime(50);
      powerUpMode(0);
      powerUpKey(0);
#ifdef BATTERY_MODE
      lowBatLimit(DEF_LOWBAT_VOLTAGE);
      critBatLimit(DEF_CRITBAT_VOLTAGE);
#endif
    }
};

DEFREGISTER(DispReg1)
class DispList1 : public RegList1<DispReg1> {
public:
  DispList1 (uint16_t addr) : RegList1<DispReg1>(addr) {}
  void defaults () {
    clear();
  }
};

DEFREGISTER(RemReg1, CREG_AES_ACTIVE, CREG_LONGPRESSTIME ,CREG_DOUBLEPRESSTIME, 0x36, 0x37, 0x38, 0x39, 0x3a, 0x3b, 0x3c, 0x3d, 0x3e, 0x3f, 0x40, 0x41, 0x42, 0x43, 0x44, 0x45, 0x46, 0x47, 0x48, 0x49, 0x4a, 0x4b, 0x4c, 0x4d, 0x4e, 0x4f, 0x50, 0x51, 0x52, 0x53, 0x54, 0x55, 0x90, 0x91)
class RemList1 : public RegList1<RemReg1> {
  public:
    RemList1 (uint16_t addr) : RegList1<RemReg1>(addr) {}

    bool showLine (uint8_t value) const {
      return this->writeRegister(0x90, 0x01, 0, value & 0xff);
    }
    bool showLine () const {
      return this->readRegister(0x90, 0x01, 0, false);
    }

    bool Alignment (uint8_t value) const {
      return this->writeRegister(0x91, value & 0xff);
    }
    uint8_t Alignment () const {
      return this->readRegister(0x91, 0);
    }

    bool TEXT1 (uint8_t value[TEXT_LENGTH]) const {
      for (int i = 0; i < TEXT_LENGTH; i++) {
        this->writeRegister(0x36 + i, value[i] & 0xff);
      }
      return true;
    }
    String TEXT1 () const {
      String a = "";
      for (int i = 0; i < TEXT_LENGTH; i++) {
        byte b = this->readRegister(0x36 + i, 0x20);
        if (b == 0x00) b = 0x20;
        a += char(b);
      }
      return a;
    }

    bool TEXT2 (uint8_t value[TEXT_LENGTH]) const {
      for (int i = 0; i < TEXT_LENGTH; i++) {
        this->writeRegister(0x46 + i, value[i] & 0xff);
      }
      return true;
    }
    String TEXT2 () const {
      String a = "";
      for (int i = 0; i < TEXT_LENGTH; i++) {
        byte b = this->readRegister(0x46 + i, 0x20);
        if (b == 0x00) b = 0x20;
        a += char(b);
      }
      return a;
    }

    void defaults () {
      clear();
      //aesActive(false);
      longPressTime(1);
      doublePressTime(0);
      uint8_t initValues[TEXT_LENGTH];
      memset(initValues, 0x00, TEXT_LENGTH);
      TEXT1(initValues);
      TEXT2(initValues);
      showLine(false);
      Alignment(AlignRight);
    }
};

class RemChannel : public RemoteChannel<Hal,PEERS_PER_CHANNEL,DispList0, RemList1>  {
public:
  RemChannel () : RemoteChannel() {}
    virtual ~RemChannel () {}
    void configChanged() {
      uint16_t _longpressTime = 300 + (this->getList1().longPressTime() * 100);
      setLongPressTime(millis2ticks(_longpressTime));

      List1Texts[(number() - 1)  * 2] = this->getList1().TEXT1();
      List1Texts[((number() - 1) * 2) + 1] = this->getList1().TEXT2();

      bool somethingChanged = (
                                DisplayLines[(number() - 1)].showLine != this->getList1().showLine() ||
                                DisplayLines[(number() - 1)].Alignment != this->getList1().Alignment()
                              );

      DisplayLines[(number() - 1)].showLine = this->getList1().showLine();
      DisplayLines[(number() - 1)].Alignment = this->getList1().Alignment();
      DPRINT(number() < 10 ? "0":"");DDEC(number()); DPRINT(F(" - TEXT1 = ")); DPRINT(this->getList1().TEXT1());DPRINT(F(" - TEXT2 = ")); DPRINT(this->getList1().TEXT2());DPRINT(F(" - Line  = ")); DDEC(this->getList1().showLine());DPRINT(F(" - Align = ")); DDECLN(this->getList1().Alignment());

      if (!runSetup && somethingChanged) ePaper.mustUpdateDisplay(true);
    }

    uint8_t flags () const {
      return hal.battery.low() ? 0x80 : 0x00;
    }
};
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
void loop() {
  bool worked = hal.runready();
  bool poll = sdev.pollRadio();
  if ( worked == false && poll == false ) {
#ifdef BATTERY_MODE
    if (hal.battery.critical()) {
      display.drawPaged(emptyBatteryDisplay);
      hal.activity.sleepForever(hal);
    }
    if (ePaper.isWaiting()) {
      hal.activity.savePower<Idle<>>(hal);
    } else {
      hal.activity.savePower<Sleep<>>(hal);
    }
#else
    hal.activity.savePower<Idle<>>(hal);
#endif
  }
}

uint16_t centerPosition(const char * text) {
  return (display.width() / 2) - (u8g2Fonts.getUTF8Width(text) / 2);
}

void PrintTextWithPosition(String text, int y)
{
  while (text.length()) {
    int pos1 = text.lastIndexOf("@p");
    int pos2 = text.lastIndexOf("@f");
    int pos = max(pos1, pos2);
    if (pos >= 0) {
      String tPos = text.substring(pos+2, pos+4); // Position als String
      String tText = text.substring(pos+4);  // Ausgabetext
      text.remove(pos);
      if (tText.length()) {
        uint16_t iPos = tPos.toInt();  // Position als int
        //Serial.print(iPos); Serial.print(" ");
        //Serial.print(tText); Serial.println(" ");
        uint16_t left = iPos * display.width() / 100u;
        u8g2Fonts.setCursor(left, y);
#ifdef USE_COLOR
        if (pos2 > pos1) {
          u8g2Fonts.setForegroundColor(GxEPD_RED);
        } else {
          u8g2Fonts.setForegroundColor(ePaper.ForegroundColor());
        }
#endif
        u8g2Fonts.print(tText);
      }
    } else {
      break;
    }
  }
#ifdef USE_COLOR
  ePaper.setDisplayColors();    // restore default colors for possible next line in loop updateDisplay()
#endif
}

void updateDisplay() {
  display.fillScreen(ePaper.BackgroundColor());
  u8g2Fonts.setFont(u8g2_font_helvB18_tf);

  for (uint16_t i = 0; i < 10; i++) {
    if (DisplayLines[i].showLine && i < 10) display.drawLine(0, ((i + 1) * 40), display.width(), ((i + 1) * 40), ePaper.ForegroundColor());
    //DisplayLines[i].Text.trim();
    String viewText = DisplayLines[i].Text;
    viewText.replace("{", "ä");
    viewText.replace("|", "ö");
    viewText.replace("}", "ü");
    viewText.replace("[", "Ä");
    viewText.replace("#", "Ö");
    viewText.replace("$", "Ü");
    viewText.replace("~", "ß");
    viewText.replace("'", "=");

    uint8_t icon_number = DisplayLines[i].Icon;
    uint16_t icon_top = (24 - ( Icons[icon_number].height / 2)) + (i * 40) - 4;

    uint16_t leftTextPos = 0xffff;
    uint16_t fontWidth = u8g2Fonts.getUTF8Width(viewText.c_str());

    bool icon_colored = DisplayLines[i].IconColored;

    uint16_t y = i * 40 + 30;

    switch (DisplayLines[i].Alignment) {
      case AlignLeft:
        // TomMajor Erweiterung x-Textposition
        if (viewText.startsWith("@p") || viewText.startsWith("@f")) {
            PrintTextWithPosition(viewText, y);
            continue;
        }
        leftTextPos = 40;
        if (icon_number != 255) display.drawBitmap(Icons[icon_number].Icon, (( 24 - Icons[icon_number].width ) / 2) + 8, icon_top, Icons[icon_number].width, Icons[icon_number].height, icon_colored ? GxEPD_RED : ePaper.ForegroundColor(), icon_colored ? GxEPD::bm_normal | GxEPD::bm_transparent | GxEPD::bm_invert : GxEPD::bm_default);
        break;
      case AlignCenterIconRight:
        leftTextPos = (display.width() / 2) - (fontWidth / 2);
        if (icon_number != 255) {
          leftTextPos -= ((Icons[icon_number].width  / 2) + 4);
          display.drawBitmap(Icons[icon_number].Icon, leftTextPos + u8g2Fonts.getUTF8Width(viewText.c_str()) + 8 + (( 24 - Icons[icon_number].width ) / 2) , icon_top, Icons[icon_number].width, Icons[icon_number].height, icon_colored ? GxEPD_RED : ePaper.ForegroundColor(), icon_colored ? GxEPD::bm_normal | GxEPD::bm_transparent | GxEPD::bm_invert : GxEPD::bm_default);
        }
        break;
      case AlignCenterIconLeft:
        leftTextPos = (display.width() / 2) - (fontWidth / 2);
        if (icon_number != 255) {
          leftTextPos += ((Icons[icon_number].width  / 2) + 4);
          display.drawBitmap(Icons[icon_number].Icon, leftTextPos - Icons[icon_number].width - 8 , icon_top, Icons[icon_number].width, Icons[icon_number].height, icon_colored ? GxEPD_RED : ePaper.ForegroundColor(), icon_colored ? GxEPD::bm_normal | GxEPD::bm_transparent | GxEPD::bm_invert : GxEPD::bm_default);
        }
        break;
      case AlignRight:
      default:
        leftTextPos = display.width() - 40 - fontWidth;
        if (icon_number != 255) display.drawBitmap(Icons[icon_number].Icon, display.width() - 32 + (( 24 - Icons[icon_number].width ) / 2) , icon_top, Icons[icon_number].width, Icons[icon_number].height, icon_colored ? GxEPD_RED : ePaper.ForegroundColor(), icon_colored ? GxEPD::bm_normal | GxEPD::bm_transparent | GxEPD::bm_invert : GxEPD::bm_default);
        break;
    }

    u8g2Fonts.setCursor(leftTextPos, y);


#ifdef USE_COLOR
    if (DisplayLines[i].TextColored == true) u8g2Fonts.setForegroundColor(GxEPD_RED);
#endif

    u8g2Fonts.print(viewText);

#ifdef USE_COLOR
    ePaper.setDisplayColors();
#endif
  }
}

void initDisplay() {
  display.fillScreen(ePaper.BackgroundColor());

  uint8_t serial[11];
  sdev.getDeviceSerial(serial);
  serial[10] = 0;

  #define TOSTRING(x) #x
  #define TOSTR(x) TOSTRING(x)

  const char * title        PROGMEM = "HB-Dis-EP-42BW";
  const char * asksinpp     PROGMEM = "AskSin++";
  const char * version      PROGMEM = "V " ASKSIN_PLUS_PLUS_VERSION;
  const char * compiledMsg  PROGMEM = "compiled on";
  const char * compiledDate PROGMEM = __DATE__ " " __TIME__;
#ifdef USE_COLOR
  const char * pages        PROGMEM = "GxGDEW042Z15_PAGES: " TOSTR(GxGDEW042Z15_PAGES);
#else
  const char * pages        PROGMEM = "GxGDEW042T2_PAGES: " TOSTR(GxGDEW042T2_PAGES);
#endif
  const char * ser                  = (char*)serial;
  const char * nomaster1    PROGMEM = "- keine Zentrale -";
  const char * nomaster2    PROGMEM = "- angelernt -";

  u8g2Fonts.setFont(u8g2_font_helvB24_tf);
  u8g2Fonts.setCursor(centerPosition(title), 95);
#ifdef USE_COLOR
  u8g2Fonts.setForegroundColor(GxEPD_RED);
#endif
  u8g2Fonts.print(title);

  u8g2Fonts.setCursor(centerPosition(asksinpp), 170);
#ifdef USE_COLOR
    u8g2Fonts.setForegroundColor(ePaper.ForegroundColor());
#endif
  u8g2Fonts.print(asksinpp);

  u8g2Fonts.setCursor(centerPosition(version), 210);
  u8g2Fonts.print(version);

  u8g2Fonts.setFont(u8g2_font_helvB12_tf);
  u8g2Fonts.setCursor(centerPosition(compiledMsg), 235);
  u8g2Fonts.print(compiledMsg);
  u8g2Fonts.setCursor(centerPosition(compiledDate), 255);
  u8g2Fonts.print(compiledDate);
#ifdef USE_COLOR
    ePaper.setDisplayColors();
#endif

  u8g2Fonts.setFont(u8g2_font_helvR10_tf);
  u8g2Fonts.setCursor(centerPosition(pages), 275);
  u8g2Fonts.print(pages);

  u8g2Fonts.setFont(u8g2_font_helvB18_tf);
  u8g2Fonts.setCursor(centerPosition(ser), 320);
  u8g2Fonts.print(ser);

  if (sdev.getList0().masterid().valid() == false) {
    u8g2Fonts.setFont(u8g2_font_helvB18_tf);
    u8g2Fonts.setCursor(centerPosition(nomaster1), 360);u8g2Fonts.print(nomaster1);
    u8g2Fonts.setCursor(centerPosition(nomaster2), 386);u8g2Fonts.print(nomaster2);
  }

#ifdef USE_COLOR
  display.drawRect(50, 138, 200, 145, GxEPD_RED);
#else
  display.drawRect(50, 138, 200, 145, ePaper.ForegroundColor());
#endif
}

void emptyBatteryDisplay() {
  display.fillScreen(ePaper.BackgroundColor());
#ifdef USE_COLOR
  uint16_t fg = GxEPD_RED;
#else
  uint16_t fg = ePaper.ForegroundColor();
#endif
  display.fillRect(120, 80, 60, 40, fg);

  uint8_t batt_x = 80;
  uint8_t batt_y = 120;
  uint8_t batt_w = 140;
  uint8_t batt_h = 230;
  uint8_t line_w = 4;

  for (uint8_t i = 0 ; i < line_w; i++) {
    display.drawRect(batt_x + i, batt_y + i, batt_w - i*2, batt_h - i*2, fg);
    display.drawLine(batt_x + i, batt_y + batt_h - 1, batt_x + batt_w - line_w + i, batt_y + 1,fg);
  }
}

void outOfHouseDisplay() {
  display.fillScreen(ePaper.BackgroundColor());
#ifdef USE_COLOR
 uint16_t fg = GxEPD_RED;
#else
 uint16_t fg = ePaper.ForegroundColor();
#endif


 uint8_t home_x = 50;
 uint8_t home_y = 150;
 uint8_t home_w = 200;
 uint8_t home_h = 230;
 uint8_t line_w = 4;

 for (uint8_t i = 0 ; i < line_w; i++) {
   display.drawRect(home_x + i, home_y + i, home_w - i*2, home_h - i*2, fg);
   display.drawLine(home_x + i, home_y + i, home_y + i , home_x + i, fg);
   display.drawLine(home_y +i , home_x + i , home_x + home_w - i, home_y - i,  fg);
 }
}

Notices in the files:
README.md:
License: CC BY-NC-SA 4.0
